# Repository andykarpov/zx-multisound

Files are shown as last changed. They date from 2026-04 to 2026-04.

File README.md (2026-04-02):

## ZX-MultiSound
Sound card for ZX Spectrum (NemoBus).

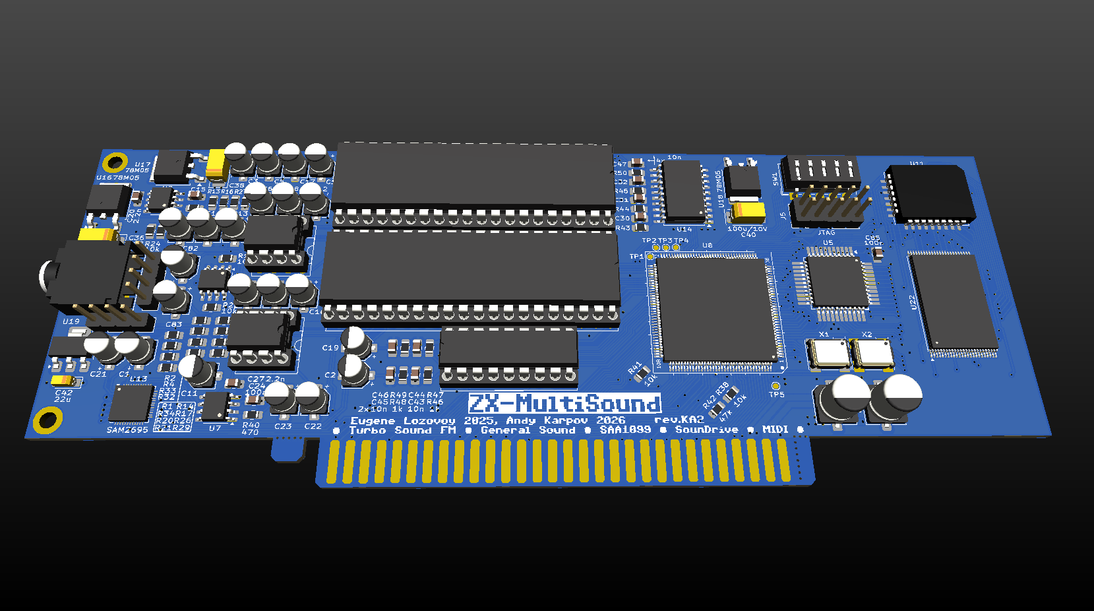
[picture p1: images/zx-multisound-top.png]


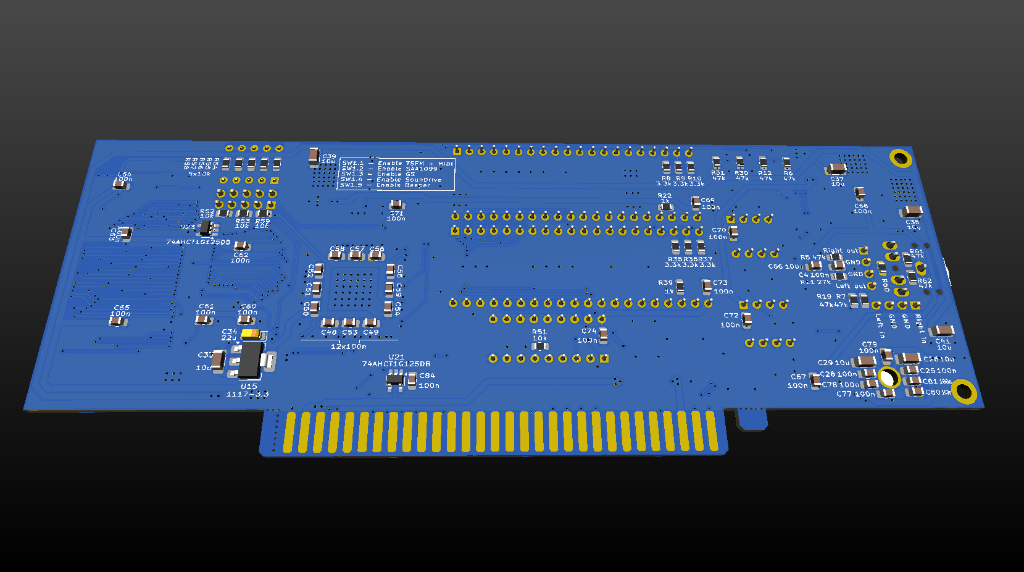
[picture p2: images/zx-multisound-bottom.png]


### Tech specs
* TurboSound FM (2xYM2203)
* General Sound (16MHz, 1024Kb of RAM)
* SAA1099 (use port #FF/#1FF to access SAA chip, write #F7/#FF to #FFFD port to enable/disable SAA)
* SounDrive (ports #0F, #1F, #4F, #5F)
* MIDI synthesizer (controlled via YM(AY) chip - compatible with ZX Spectrum 128K / ZXUNO)
* Low profile PCB: 170x64mm
* 5V and 12V power required
* 4x 1-bit digital DACs for GS and SounDrive

### Changelog & current status
* Rev.A - first release. Please note the [errata](pcb/rev.A/ERRATA.txt);
* Rev.A1 - fixed known rev.A issues. Please note the [errata](pcb/rev.A1/ERRATA.txt).
* Rev.A2:
    * Fixed Z80 clocking - added buffer;
    * Fixed 3.5mm jack footprint swapped left-right channels;
    * Fixed misplaced R20 and R34 labels on silkscreen;
    * 74LVC1G125DB replaced by 74AHCT1G125DB;
    * C3,C5,C17,C18 slightly moved left;
    * Added ledge on edge connector;
    * Improved SAM2695 footprint for hand soldering.
* Rev.KA2:
    * Single SRAM chip 2mb

Sound card has been tested only with ZX Evolution. You can use it with another computer at your own risk.

### Related projects
* Turbo Sound FM - [link](http://www.nedopc.com/TURBOSOUND/ts-fm.php)
* ZXM-SoundCard - [link](http://micklab.ru/My%20Soundcard/ZXMSoundCard.htm)
* ZXM-GeneralSound - [link](http://micklab.ru/My%20Soundcard/ZXMGeneralSound.htm)
* NeoGS - [link](http://www.nedopc.com/gs/ngs.php)

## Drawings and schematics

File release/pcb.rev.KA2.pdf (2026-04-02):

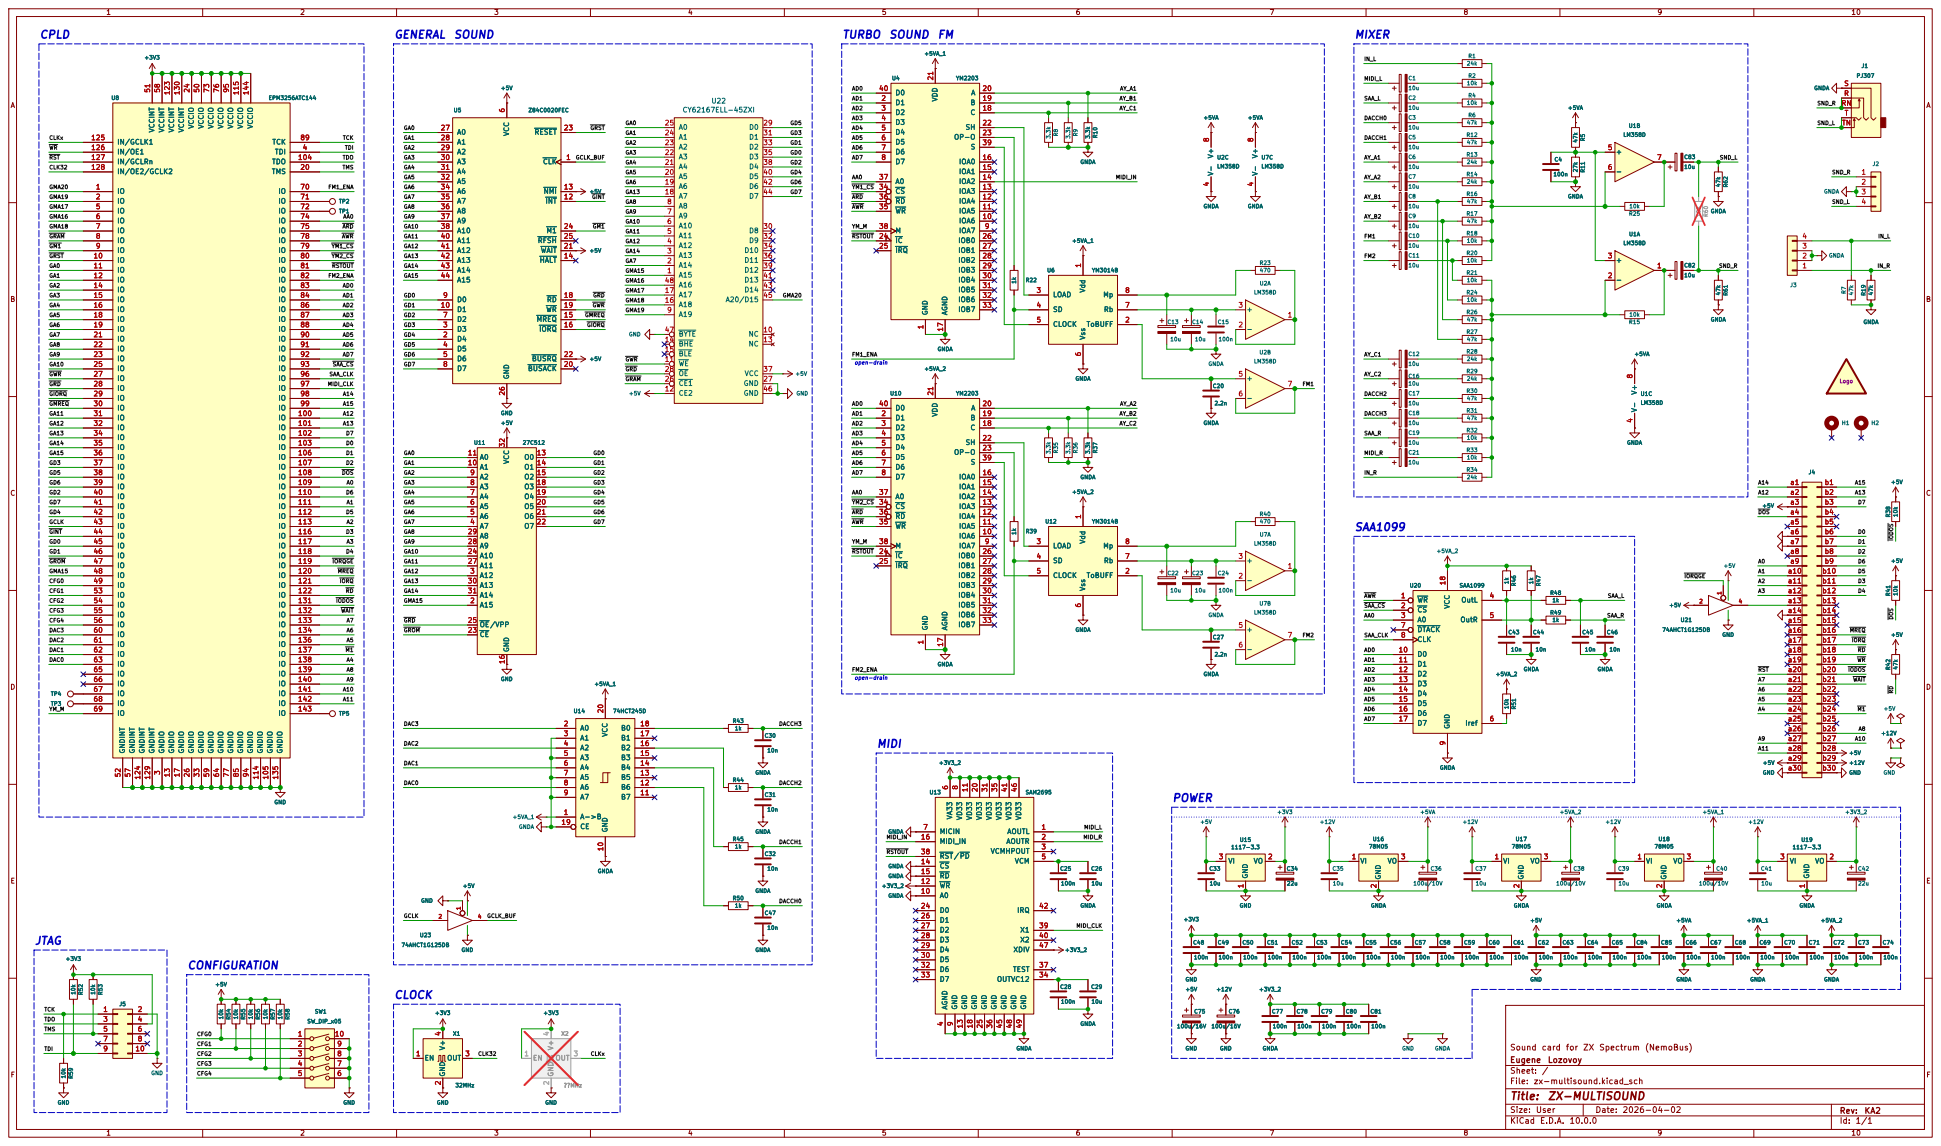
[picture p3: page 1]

open-drain TURBO SOUND FM

Sound card for ZX Spectrum (NemoBus)
Eugene Lozovoy
Sheet: /
F Date: 2026-04-02 KiCad E.D.A. 10.0.0
File: zx-multisound.kicad_sch
Title: ZX-MULTISOUND

GND

Size: User | Rev: KA2

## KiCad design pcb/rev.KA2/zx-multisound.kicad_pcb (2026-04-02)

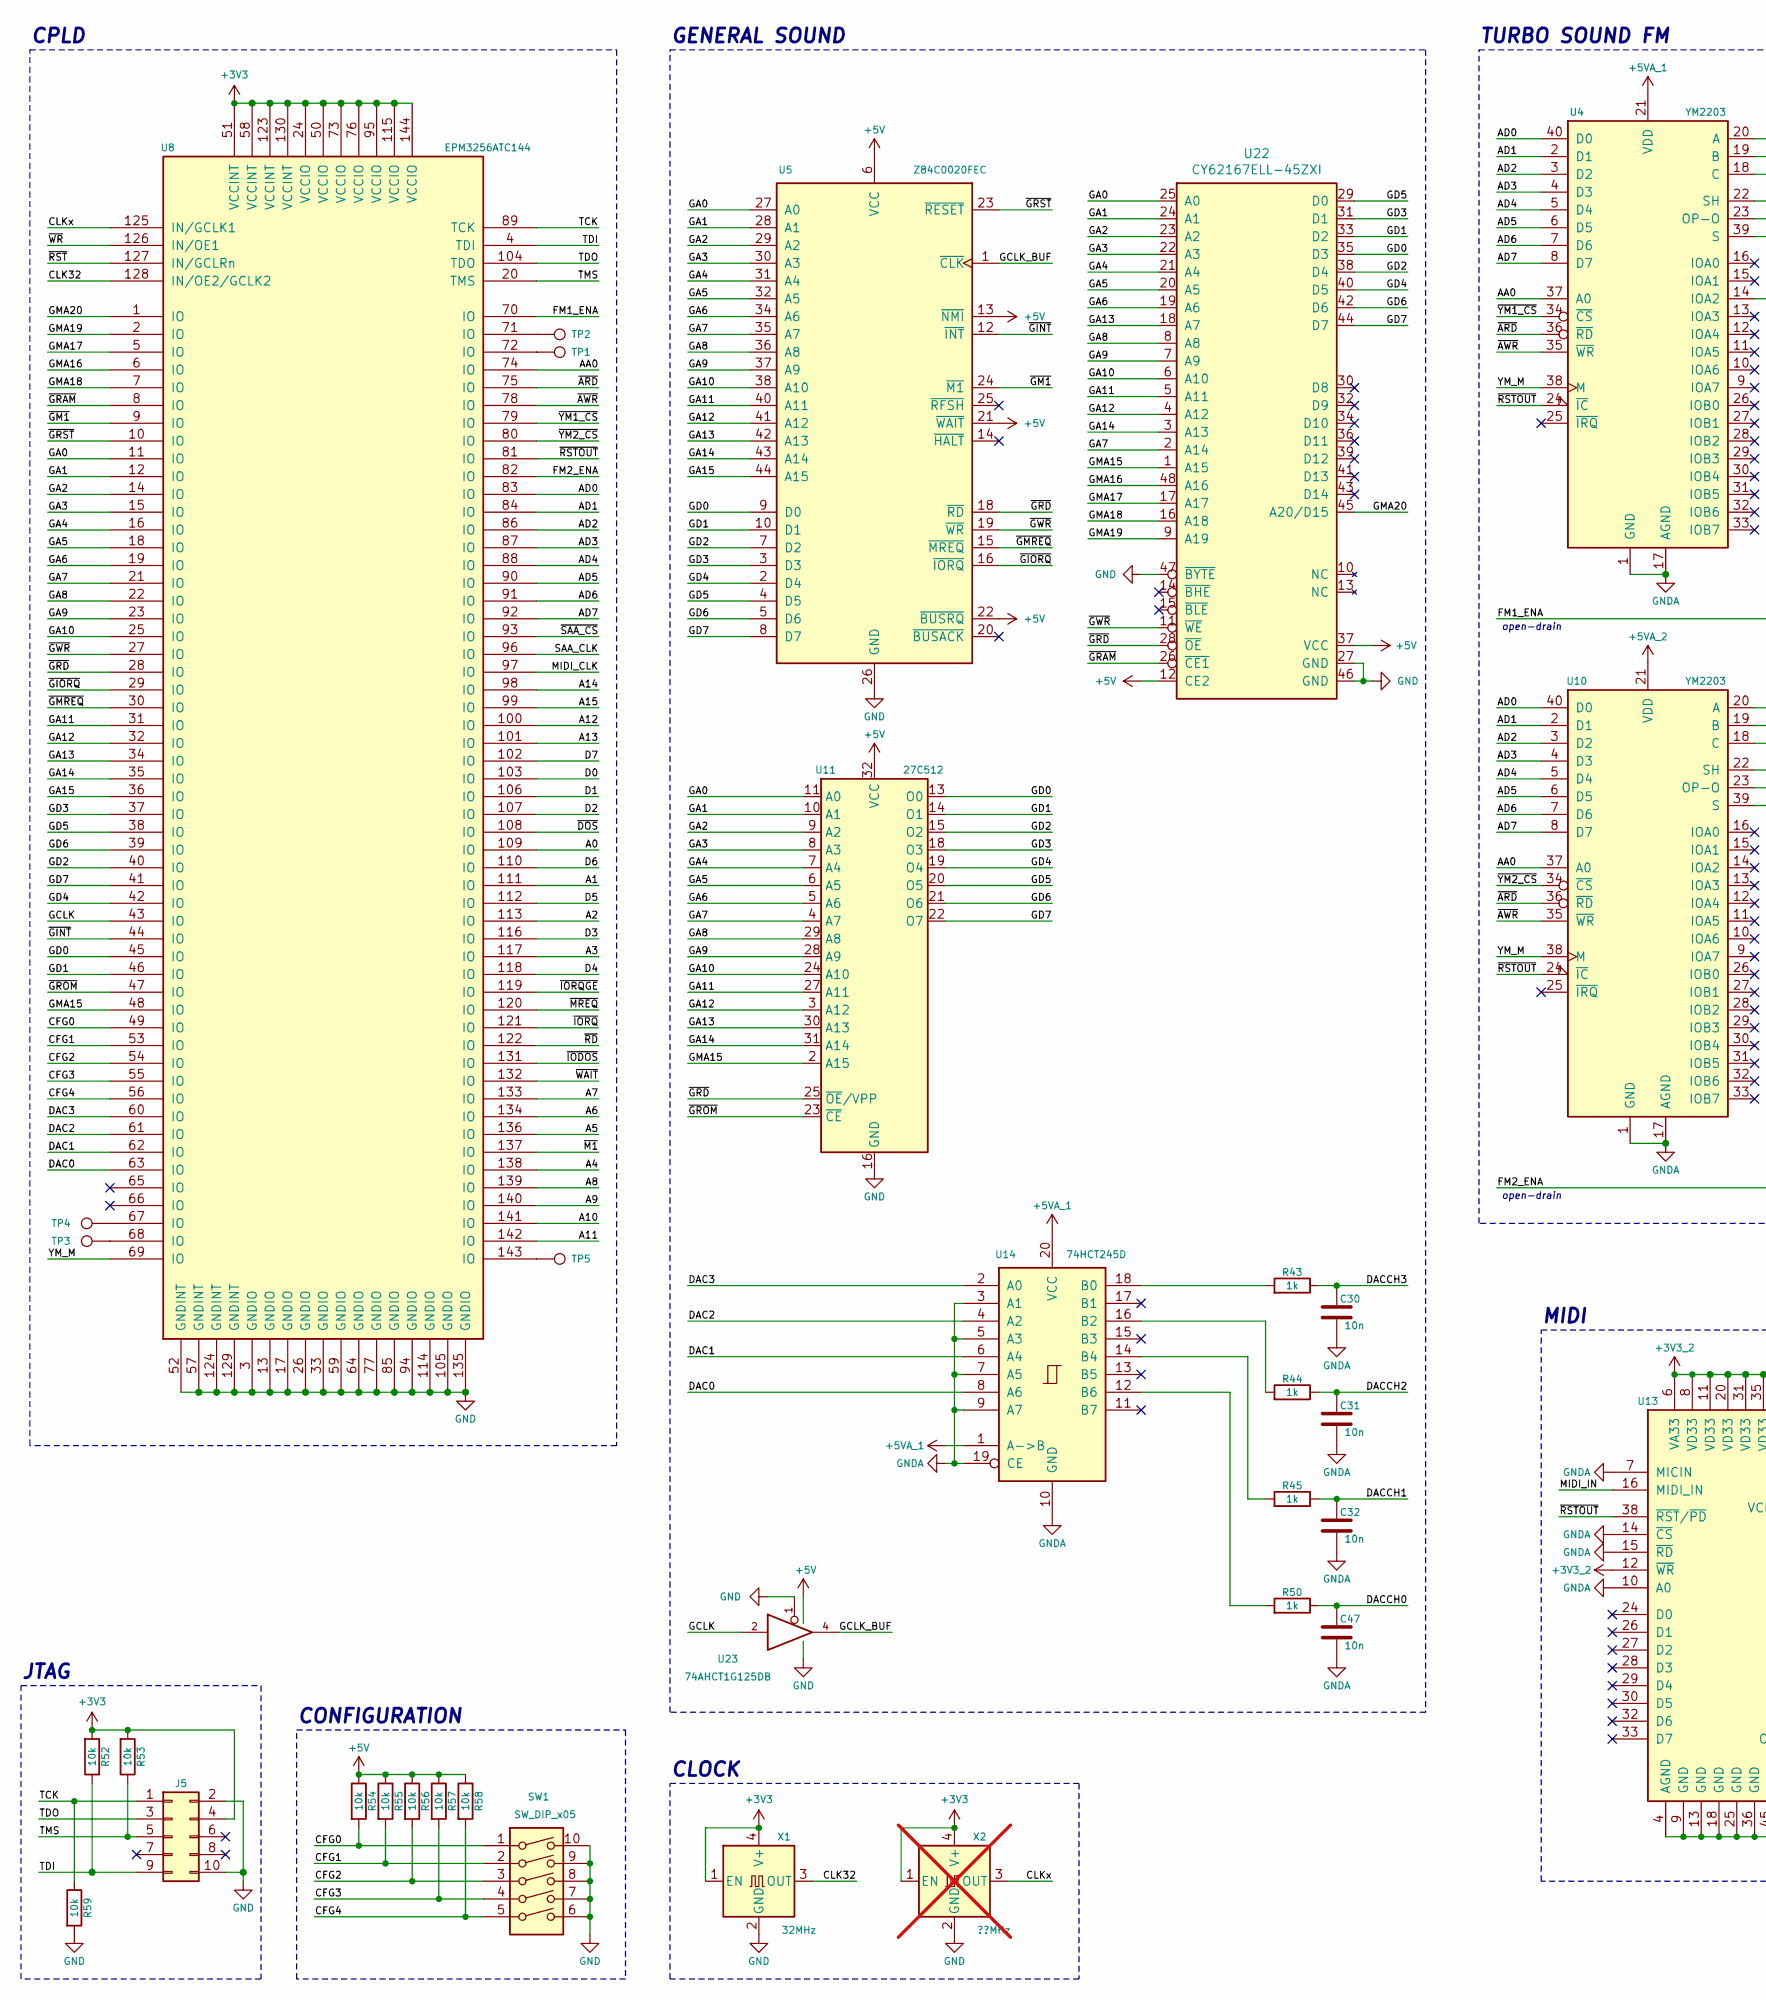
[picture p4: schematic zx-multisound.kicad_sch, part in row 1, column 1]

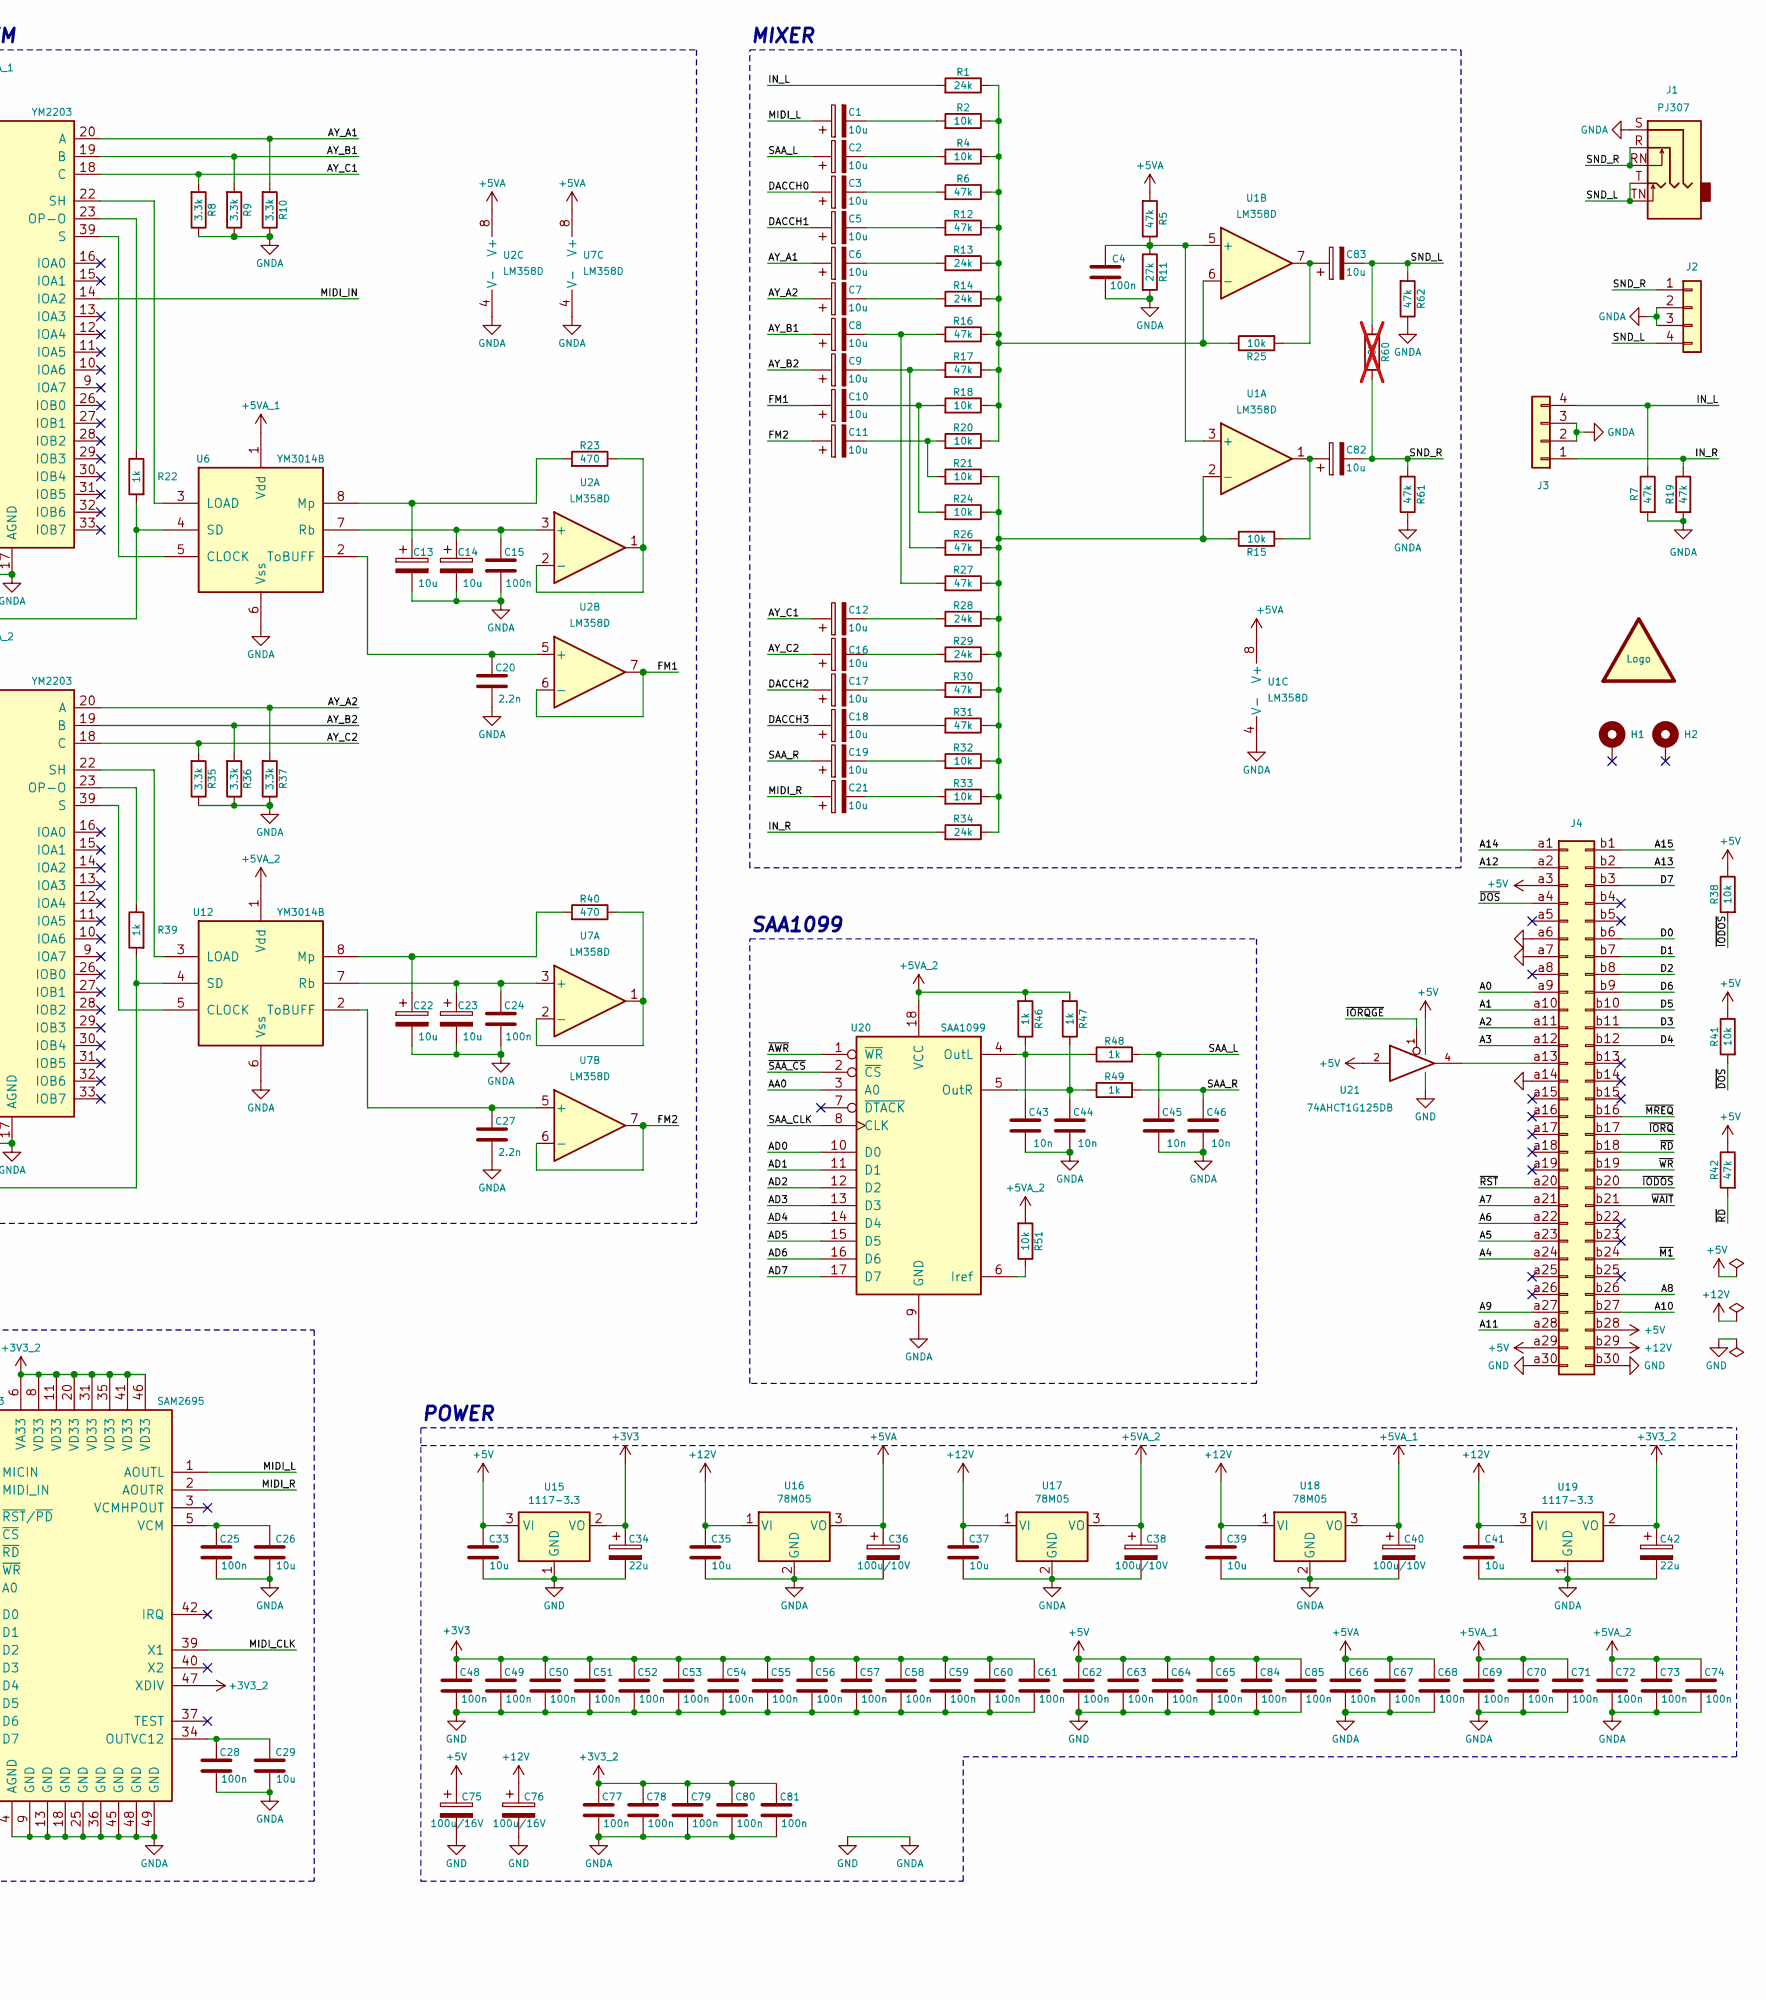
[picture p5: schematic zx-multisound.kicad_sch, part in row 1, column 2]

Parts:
C1, C2, C3, C5, C6, C7, C8, C9, C10, C11, C12, C13, C14, C16, C17, C18, C19, C21, C22, C23, C82, C83: 10u; CP_Elec_4x5.4
C4, C15, C24, C25, C28, C48, C49, C50, C51, C52, C53, C54, C55, C56, C57, C58, C59, C60, C61, C62, C63, C64, C65, C66, C67, C68, C69, C70, C71, C72, C73, C74, C77, C78, C79, C80, C81, C84, C85: 100n; C_0805_2012Metric_Pad1.18x1.45mm_HandSolder
C20, C27: 2.2n; C_0805_2012Metric_Pad1.18x1.45mm_HandSolder
C26, C29, C33, C35, C37, C39, C41: 10u; C_1206_3216Metric_Pad1.33x1.80mm_HandSolder
C30, C31, C32, C43, C44, C45, C46, C47: 10n; C_0805_2012Metric_Pad1.18x1.45mm_HandSolder
C34, C42: 22u; CP_EIA-3216-18_Kemet-A_Pad1.58x1.35mm_HandSolder
C36, C38, C40: 100u/10V; CP_EIA-6032-28_Kemet-C_Pad2.25x2.35mm_HandSolder
C75, C76: 100u/16V; CP_Elec_6.3x7.7
H1, H2: MountingHole_Pad; MountingHole_2.7mm_M2.5_DIN965_Pad
J1: PJ307; PJ-307
J2, J3: Conn_01x04; PinHeader_1x04_P2.54mm_Vertical
J4: Conn_02x30_Row_Letter_First; ZX_NEMO_60_EDGE
J5: Conn_02x05_Odd_Even; PinHeader_2x05_P2.54mm_Vertical
LOGO1: graphic; black-mage-12.5x8.6
R1, R13, R14, R28, R29, R34: 24k; R_0805_2012Metric_Pad1.20x1.40mm_HandSolder
R2, R4, R15, R18, R20, R21, R24, R25, R32, R33, R38, R41, R51, R52, R53, R54, R55, R56, R57, R58, R59: 10k; R_0805_2012Metric_Pad1.20x1.40mm_HandSolder
R5, R6, R7, R12, R16, R17, R19, R26, R27, R30, R31, R42, R61, R62: 47k; R_0805_2012Metric_Pad1.20x1.40mm_HandSolder
R8, R9, R10, R35, R36, R37: 3.3k; R_0805_2012Metric_Pad1.20x1.40mm_HandSolder
R11: 27k; R_0805_2012Metric_Pad1.20x1.40mm_HandSolder
R22, R39, R43, R44, R45, R46, R47, R48, R49, R50: 1k; R_0805_2012Metric_Pad1.20x1.40mm_HandSolder
R23, R40: 470; R_0805_2012Metric_Pad1.20x1.40mm_HandSolder
R60: 10K; R_0805_2012Metric_Pad1.20x1.40mm_HandSolder; not fitted
SW1: SW_DIP_x05; SW_DIP_SPSTx05_Slide_6.7x14.26mm_W7.62mm_P2.54mm_LowProfile
TP1, TP2, TP3, TP4, TP5: TestPoint; TestPoint_Pad_D1.0mm
U1, U2, U7: LM358D; SOIC-8_3.9x4.9mm_P1.27mm
U4, U10: YM2203; DIP-40_W15.24mm_Socket
U5: Z84C0020FEC; TQFP-44_14x14mm_P0.8mm
U6, U12: YM3014B; DIP-8_W7.62mm_Socket
U8: EPM3256ATC144; TQFP-144_20x20mm_P0.5mm
U11: 27C512; PLCC-32_11.4x14.0mm_P1.27mm-longpads
U13: SAM2695; QFN-48-1EP_6x6mm_P0.4mm_EP4.2x4.2mm
U14: 74HCT245D; SOIC-20W_7.5x12.8mm_P1.27mm
U15, U19: 1117-3.3; SOT-223-3_TabPin2
U16, U17, U18: 78M05; TO-252-2
U20: SAA1099; DIP-18_W7.62mm_Socket
U21, U23: 74AHCT1G125DB; SOT-23-5_HandSoldering
U22: CY62167ELL-45ZXI; TSOP-I-48_18.4x12mm_P0.5mm
X1: 32MHz; Oscillator_SMD_7050_7.0x5.0mm
X2: ??MHz; Oscillator_SMD_7050_7.0x5.0mm; not fitted

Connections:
+3V3: C34.1, C48.1, C49.1, C50.1, C51.1, C52.1, C53.1, C54.1, C55.1, C56.1, C57.1, C58.1, C59.1, C60.2, C61.2, J5.4, R52.2, R53.2, U8.24 (VCCIO), U8.50 (VCCIO), U8.51 (VCCINT), U8.58 (VCCINT), U8.73 (VCCIO), U8.76 (VCCIO), U8.95 (VCCIO), U8.115 (VCCIO), U8.123 (VCCINT), U8.130 (VCCINT), U8.144 (VCCIO), U15.2 (VO), X1.1 (EN), X1.4 (V+), X2.1 (EN), X2.4 (V+)
+3V3_2: C42.1, C77.1, C78.1, C79.1, C80.1, C81.1, U13.6 (VA33), U13.8 (VD33), U13.11 (VD33), U13.12 (~WR), U13.20 (VD33), U13.31 (VD33), U13.35 (VD33), U13.41 (VD33), U13.46 (VD33), U13.47 (XDIV), U19.2 (VO)
+5V: C33.1, C62.2, C63.2, C64.2, C65.2, C75.1, C84.2, C85.2, J4.a3, J4.a29, J4.b28, R38.1, R41.1, R42.1, R54.1, R55.1, R56.1, R57.1, R58.1, U5.6 (VCC), U5.13 (~NMI), U5.21 (~WAIT), U5.22 (~BUSRQ), U11.32 (VCC), U15.3 (VI), U21.2, U21.5 (VCC), U22.12 (CE2), U22.37 (VCC), U23.5 (VCC)
+5VA: C36.1, C66.2, C67.2, C68.2, R5.2, U1.8 (V+), U2.8 (V+), U7.8 (V+), U16.3 (VO)
+5VA_1: C40.1, C69.2, C70.2, C71.2, U4.21 (VDD), U6.1 (Vdd), U14.1 (A->B), U14.20 (VCC), U18.3 (VO)
+5VA_2: C38.1, C72.2, C73.2, C74.2, R46.2, R47.2, R51.2, U10.21 (VDD), U12.1 (Vdd), U17.3 (VO), U20.18 (VCC)
+12V: C35.1, C37.1, C39.1, C41.1, C76.1, J4.b29, U16.1 (VI), U17.1 (VI), U18.1 (VI), U19.3 (VI)
/A0: J4.a9, U8.109 (IO)
/A1: J4.a10, U8.111 (IO)
/A2: J4.a11, U8.113 (IO)
/A3: J4.a12, U8.117 (IO)
/A4: J4.a24, U8.138 (IO)
/A5: J4.a23, U8.136 (IO)
/A6: J4.a22, U8.134 (IO)
/A7: J4.a21, U8.133 (IO)
/A8: J4.b26, U8.139 (IO)
/A9: J4.a27, U8.140 (IO)
/A10: J4.b27, U8.141 (IO)
/A11: J4.a28, U8.142 (IO)
/A12: J4.a2, U8.100 (IO)
/A13: J4.b2, U8.101 (IO)
/A14: J4.a1, U8.98 (IO)
/A15: J4.b1, U8.99 (IO)
/AA0: U4.37 (A0), U8.74 (IO), U10.37 (A0), U20.3 (A0)
/AD0: U4.40 (D0), U8.83 (IO), U10.40 (D0), U20.10 (D0)
/AD1: U4.2 (D1), U8.84 (IO), U10.2 (D1), U20.11 (D1)
/AD2: U4.3 (D2), U8.86 (IO), U10.3 (D2), U20.12 (D2)
/AD3: U4.4 (D3), U8.87 (IO), U10.4 (D3), U20.13 (D3)
/AD4: U4.5 (D4), U8.88 (IO), U10.5 (D4), U20.14 (D4)
/AD5: U4.6 (D5), U8.90 (IO), U10.6 (D5), U20.15 (D5)
/AD6: U4.7 (D6), U8.91 (IO), U10.7 (D6), U20.16 (D6)
/AD7: U4.8 (D7), U8.92 (IO), U10.8 (D7), U20.17 (D7)
/AY_A1: C6.1, R10.2, U4.20 (A)
/AY_A2: C7.1, R37.2, U10.20 (A)
/AY_B1: C8.1, R9.2, U4.19 (B)
/AY_B2: C9.1, R36.2, U10.19 (B)
/AY_C1: C12.1, R8.2, U4.18 (C)
/AY_C2: C16.1, R35.2, U10.18 (C)
/CFG0: R54.2, SW1.1, U8.49 (IO)
/CFG1: R55.2, SW1.2, U8.53 (IO)
/CFG2: R56.2, SW1.3, U8.54 (IO)
/CFG3: R57.2, SW1.4, U8.55 (IO)
/CFG4: R58.2, SW1.5, U8.56 (IO)
/CLK32: U8.128 (IN/OE2/GCLK2), X1.3 (OUT)
/CLKx: U8.125 (IN/GCLK1), X2.3 (OUT)
/D0: J4.b6, U8.103 (IO)
/D1: J4.b7, U8.106 (IO)
/D2: J4.b8, U8.107 (IO)
/D3: J4.b11, U8.116 (IO)
/D4: J4.b12, U8.118 (IO)
/D5: J4.b10, U8.112 (IO)
/D6: J4.b9, U8.110 (IO)
/D7: J4.b3, U8.102 (IO)
/DAC0: U8.63 (IO), U14.8 (A6)
/DAC1: U8.62 (IO), U14.6 (A4)
/DAC2: U8.61 (IO), U14.4 (A2)
/DAC3: U8.60 (IO), U14.2 (A0)
/DACCH0: C3.1, C47.1, R50.1
/DACCH1: C5.1, C32.1, R45.1
/DACCH2: C17.1, C31.1, R44.1
/DACCH3: C18.1, C30.1, R43.1
/FM1: C10.1, U2.6 (-), U2.7
/FM1_ENA: R22.2, U6.4 (SD), U8.70 (IO)
/FM2: C11.1, U7.6 (-), U7.7
/FM2_ENA: R39.2, U8.82 (IO), U12.4 (SD)
/GA0: U5.27 (A0), U8.11 (IO), U11.11 (A0), U22.25 (A0)
/GA1: U5.28 (A1), U8.12 (IO), U11.10 (A1), U22.24 (A1)
/GA2: U5.29 (A2), U8.14 (IO), U11.9 (A2), U22.23 (A2)
/GA3: U5.30 (A3), U8.15 (IO), U11.8 (A3), U22.22 (A3)
/GA4: U5.31 (A4), U8.16 (IO), U11.7 (A4), U22.21 (A4)
/GA5: U5.32 (A5), U8.18 (IO), U11.6 (A5), U22.20 (A5)
/GA6: U5.34 (A6), U8.19 (IO), U11.5 (A6), U22.19 (A6)
/GA7: U5.35 (A7), U8.21 (IO), U11.4 (A7), U22.2 (A14)
/GA8: U5.36 (A8), U8.22 (IO), U11.29 (A8), U22.8 (A8)
/GA9: U5.37 (A9), U8.23 (IO), U11.28 (A9), U22.7 (A9)
/GA10: U5.38 (A10), U8.25 (IO), U11.24 (A10), U22.6 (A10)
/GA11: U5.40 (A11), U8.31 (IO), U11.27 (A11), U22.5 (A11)
/GA12: U5.41 (A12), U8.32 (IO), U11.3 (A12), U22.4 (A12)
/GA13: U5.42 (A13), U8.34 (IO), U11.30 (A13), U22.18 (A7)
/GA14: U5.43 (A14), U8.35 (IO), U11.31 (A14), U22.3 (A13)
/GA15: U5.44 (A15), U8.36 (IO)
/GCLK: U8.43 (IO), U23.2
/GCLK_BUF: U5.1 (~CLK), U23.4
/GD0: U5.9 (D0), U8.45 (IO), U11.13 (O0), U22.35 (D3)
/GD1: U5.10 (D1), U8.46 (IO), U11.14 (O1), U22.33 (D2)
/GD2: U5.7 (D2), U8.40 (IO), U11.15 (O2), U22.38 (D4)
/GD3: U5.3 (D3), U8.37 (IO), U11.18 (O3), U22.31 (D1)
/GD4: U5.2 (D4), U8.42 (IO), U11.19 (O4), U22.40 (D5)
/GD5: U5.4 (D5), U8.38 (IO), U11.20 (O5), U22.29 (D0)
/GD6: U5.5 (D6), U8.39 (IO), U11.21 (O6), U22.42 (D6)
/GD7: U5.8 (D7), U8.41 (IO), U11.22 (O7), U22.44 (D7)
/GMA15: U8.48 (IO), U11.2 (A15), U22.1 (A15)
/GMA16: U8.6 (IO), U22.48 (A16)
/GMA17: U8.5 (IO), U22.17 (A17)
/GMA18: U8.7 (IO), U22.16 (A18)
/GMA19: U8.2 (IO), U22.9 (A19)
/GMA20: U8.1 (IO), U22.45 (A20/D15)
/IN_L: J3.4, R1.2, R7.1
/IN_R: J3.1, R19.1, R34.2
/MIDI_CLK: U8.97 (IO), U13.39 (X1)
/MIDI_IN: U4.14 (IOA2), U13.16 (MIDI_IN)
/MIDI_L: C1.1, U13.1 (AOUTL)
/MIDI_R: C21.1, U13.2 (AOUTR)
/SAA_CLK: U8.96 (IO), U20.8 (CLK)
/SAA_L: C2.1, C45.1, R48.2
/SAA_R: C19.1, C46.1, R49.2
/SND_L: C83.2, J1.T, J1.TN, J2.4, R60.2, R62.2
/SND_R: C82.2, J1.R, J1.RN, J2.1, R60.1, R61.2
/TCK: J5.1, R59.1, U8.89 (TCK)
/TDI: J5.9, R52.1, U8.4 (TDI)
/TDO: J5.3, U8.104 (TDO)
/TMS: J5.5, R53.1, U8.20 (TMS)
/YM_M: U4.38 (M), U8.69 (IO), U10.38 (M)
/~ARD: U4.36 (~RD), U8.75 (IO), U10.36 (~RD)
/~AWR: U4.35 (~WR), U8.78 (IO), U10.35 (~WR), U20.1 (~WR)
/~DOS: J4.a4, R41.2, U8.108 (IO)
/~GINT: U5.12 (~INT), U8.44 (IO)
/~GIORQ: U5.16 (~IORQ), U8.29 (IO)
/~GM1: U5.24 (~M1), U8.9 (IO)
/~GMREQ: U5.15 (~MREQ), U8.30 (IO)
/~GRAM: U8.8 (IO), U22.26 (~CE1)
/~GRD: U5.18 (~RD), U8.28 (IO), U11.25 (~OE/VPP), U22.28 (~OE)
/~GROM: U8.47 (IO), U11.23 (~CE)
/~GRST: U5.23 (~RESET), U8.10 (IO)
/~GWR: U5.19 (~WR), U8.27 (IO), U22.11 (~WE)
/~IODOS: J4.b20, R38.2, U8.131 (IO)
/~IORQGE: U8.119 (IO), U21.1
/~IORQ: J4.b17, U8.121 (IO)
/~M1: J4.b24, U8.137 (IO)
/~MREQ: J4.b16, U8.120 (IO)
/~RD: J4.b18, R42.2, U8.122 (IO)
/~RSTOUT: U4.24 (~IC), U8.81 (IO), U10.24 (~IC), U13.38 (~RST/~PD)
/~RST: J4.a20, U8.127 (IN/GCLRn)
/~SAA_CS: U8.93 (IO), U20.2 (~CS)
/~WAIT: J4.b21, U8.132 (IO)
/~WR: J4.b19, U8.126 (IN/OE1)
/~YM1_CS: U4.34 (~CS), U8.79 (IO)
/~YM2_CS: U8.80 (IO), U10.34 (~CS)
GND: C4.1, C13.2, C14.2, C15.2, C20.2, C22.2, C23.2, C24.2, C25.2, C26.2, C27.2, C28.2, C29.2, C30.2, C31.2, C32.2, C33.2, C34.2, C35.2, C36.2, C37.2, C38.2, C39.2, C40.2, C41.2, C42.2, C43.2, C44.2, C45.2, C46.2, C47.2, C48.2, C49.2, C50.2, C51.2, C52.2, C53.2, C54.2, C55.2, C56.2, C57.2, C58.2, C59.2, C60.1, C61.1, C62.1, C63.1, C64.1, C65.1, C66.1, C67.1, C68.1, C69.1, C70.1, C71.1, C72.1, C73.1, C74.1, C75.2, C76.2, C77.2, C78.2, C79.2, C80.2, C81.2, C84.1, C85.1, J1.S, J2.2, J2.3, J3.2, J3.3, J4.a6, J4.a7, J4.a14, J4.a30, J4.b30, J5.2, J5.10, R7.2, R8.1, R9.1, R10.1, R11.2, R19.2, R35.1, R36.1, R37.1, R59.2, R61.1, R62.1, SW1.6, SW1.7, SW1.8, SW1.9, SW1.10, U1.4 (V-), U2.4 (V-), U4.1 (GND), U4.17 (AGND), U5.26 (GND), U6.6 (Vss), U7.4 (V-), U8.3 (GNDIO), U8.13 (GNDIO), U8.17 (GNDIO), U8.26 (GNDIO), U8.33 (GNDIO), U8.52 (GNDINT), U8.57 (GNDINT), U8.59 (GNDIO), U8.64 (GNDIO), U8.77 (GNDIO), U8.85 (GNDIO), U8.94 (GNDIO), U8.105 (GNDIO), U8.114 (GNDIO), U8.124 (GNDINT), U8.129 (GNDINT), U8.135 (GNDIO), U10.1 (GND), U10.17 (AGND), U11.16 (GND), U12.6 (Vss), U13.4 (AGND), U13.7 (MICIN), U13.9 (GND), U13.10 (A0), U13.13 (GND), U13.14 (~CS), U13.15 (~RD), U13.18 (GND), U13.25 (GND), U13.36 (GND), U13.45 (GND), U13.48 (GND), U13.49 (GND), U14.3 (A1), U14.5 (A3), U14.7 (A5), U14.9 (A7), U14.10 (GND), U14.19 (CE), U15.1 (GND), U16.2 (GND), U17.2 (GND), U18.2 (GND), U19.1 (GND), U20.9 (GND), U21.3 (GND), U22.27 (GND), U22.46 (GND), U22.47 (~BYTE), U23.1, U23.3 (GND), X1.2 (GND), X2.2 (GND)
unnamed: C1.2, R2.2
unnamed: C2.2, R4.2
unnamed: C3.2, R6.2
unnamed: C5.2, R12.2
unnamed: C6.2, R13.2
unnamed: C7.2, R14.2
unnamed: C8.2, R16.2, R27.2
unnamed: C9.2, R17.2, R26.2
unnamed: C10.2, R18.2, R24.2
unnamed: C11.2, R20.2, R21.2
unnamed: C12.2, R28.2
unnamed: C16.2, R29.2
unnamed: C17.2, R30.2
unnamed: C18.2, R31.2
unnamed: C19.2, R32.2
unnamed: C21.2, R33.2
unnamed: C82.1, R15.2, U1.1
unnamed: C83.1, R25.2, U1.7
unnamed: J4.a13, U21.4
unnamed: TP1.1 (1_1), U8.72 (IO)
unnamed: TP2.1 (1_1), U8.71 (IO)
unnamed: TP3.1 (1_1), U8.68 (IO)
unnamed: TP4.1 (1_1), U8.67 (IO)
unnamed: TP5.1 (1_1), U8.143 (IO)
unnamed: C4.2, R5.1, R11.1, U1.3 (+), U1.5 (+)
unnamed: R15.1, R21.1, R24.1, R26.1, R27.1, R28.1, R29.1, R30.1, R31.1, R32.1, R33.1, R34.1, U1.2 (-)
unnamed: R1.1, R2.1, R4.1, R6.1, R12.1, R13.1, R14.1, R16.1, R17.1, R18.1, R20.1, R25.1, U1.6 (-)
unnamed: C14.1, C15.1, U2.3 (+), U6.7 (Rb)
unnamed: R23.1, U2.1, U2.2 (-)
unnamed: C20.1, U2.5 (+), U6.2 (ToBUFF)
unnamed: R22.1, U4.23 (OP-O)
unnamed: U4.39 (S), U6.5 (CLOCK)
unnamed: U4.22 (SH), U6.3 (LOAD)
unnamed: C13.1, R23.2, U6.8 (Mp)
unnamed: R40.1, U7.1, U7.2 (-)
unnamed: R39.1, U10.23 (OP-O)
unnamed: U10.39 (S), U12.5 (CLOCK)
unnamed: U10.22 (SH), U12.3 (LOAD)
unnamed: C22.1, R40.2, U12.8 (Mp)
unnamed: C23.1, C24.1, U7.3 (+), U12.7 (Rb)
unnamed: C27.1, U7.5 (+), U12.2 (ToBUFF)
unnamed: C28.1, C29.1, U13.34 (OUTVC12)
unnamed: C25.1, C26.1, U13.5 (VCM)
unnamed: R43.2, U14.18 (B0)
unnamed: R44.2, U14.16 (B2)
unnamed: R45.2, U14.14 (B4)
unnamed: R50.2, U14.12 (B6)
unnamed: R51.1, U20.6 (Iref)
unnamed: C43.1, R46.1, R48.1, U20.4 (OutL)
unnamed: C44.1, R47.1, R49.1, U20.5 (OutR)

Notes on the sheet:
SAA1099
CONFIGURATION
open-drain
GENERAL SOUND
TURBO SOUND FM
MIXER
CPLD
JTAG
POWER
MIDI
CLOCK

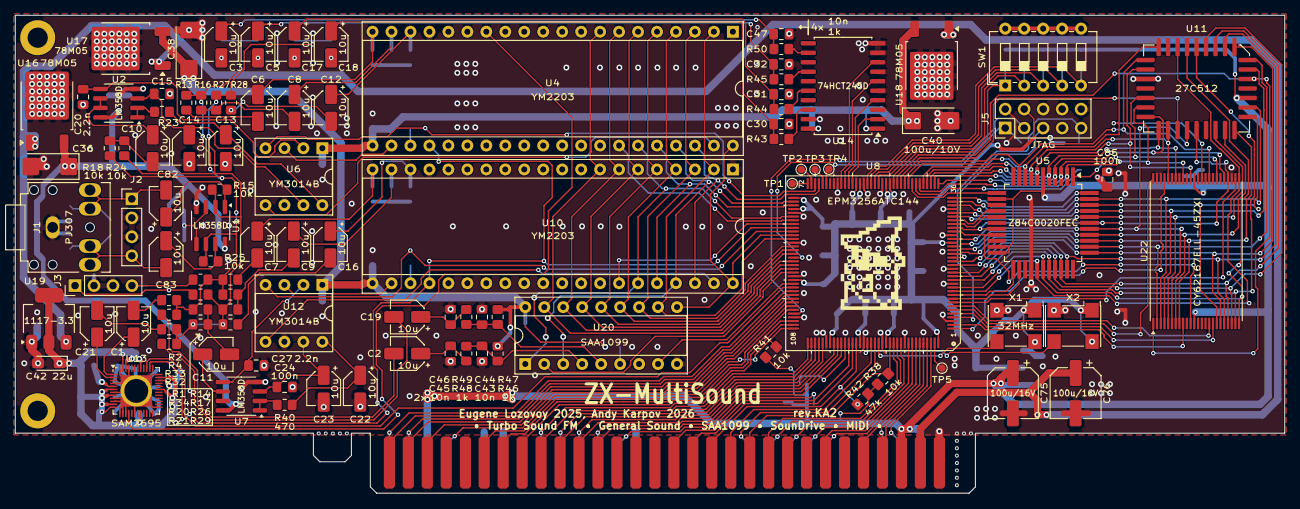
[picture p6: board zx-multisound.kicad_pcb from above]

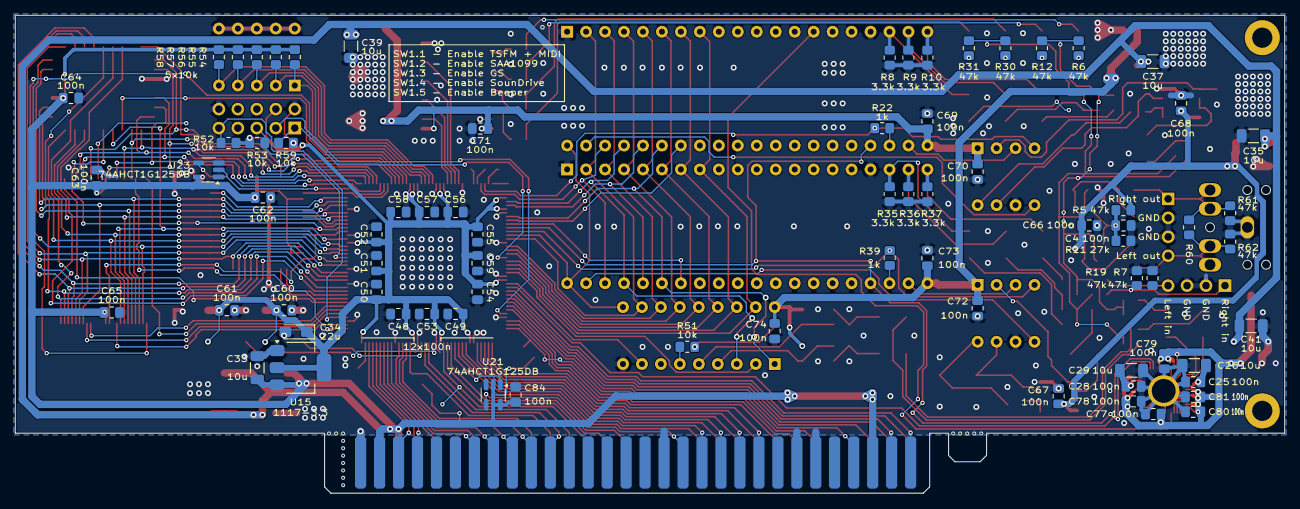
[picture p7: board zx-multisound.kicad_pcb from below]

Board: 2 copper layers, 170.0 x 64.0 mm, 183 parts (75 on the bottom side), 189 nets.

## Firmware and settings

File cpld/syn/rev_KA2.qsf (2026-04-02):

# -------------------------------------------------------------------------- #
#
# Copyright (C) 1991-2013 Altera Corporation
# Your use of Altera Corporation's design tools, logic functions 
# and other software and tools, and its AMPP partner logic 
# functions, and any output files from any of the foregoing 
# (including device programming or simulation files), and any 
# associated documentation or information are expressly subject 
# to the terms and conditions of the Altera Program License 
# Subscription Agreement, Altera MegaCore Function License 
# Agreement, or other applicable license agreement, including, 
# without limitation, that your use is for the sole purpose of 
# programming logic devices manufactured by Altera and sold by 
# Altera or its authorized distributors.  Please refer to the 
# applicable agreement for further details.
#
# -------------------------------------------------------------------------- #
#
# Quartus II 64-Bit
# Version 13.0.1 Build 232 06/12/2013 Service Pack 1 SJ Full Version
# Date created = 12:04:27  October 04, 2020
#
# -------------------------------------------------------------------------- #
#
# Notes:
#
# 1) The default values for assignments are stored in the file:
#		zx_multisound_assignment_defaults.qdf
#    If this file doesn't exist, see file:
#		assignment_defaults.qdf
#
# 2) Altera recommends that you do not modify this file. This
#    file is updated automatically by the Quartus II software
#    and any changes you make may be lost or overwritten.
#
# -------------------------------------------------------------------------- #


set_global_assignment -name FAMILY MAX3000A
set_global_assignment -name DEVICE "EPM3256ATC144-10"
set_global_assignment -name TOP_LEVEL_ENTITY zx_multisound
set_global_assignment -name ORIGINAL_QUARTUS_VERSION "13.0 SP1"
set_global_assignment -name PROJECT_CREATION_TIME_DATE "12:04:27  OCTOBER 04, 2020"
set_global_assignment -name LAST_QUARTUS_VERSION "13.0 SP1"
set_global_assignment -name PROJECT_OUTPUT_DIRECTORY output
set_global_assignment -name DEVICE_FILTER_PIN_COUNT 144
set_global_assignment -name ERROR_CHECK_FREQUENCY_DIVISOR "-1"
set_global_assignment -name SDC_FILE clocks.sdc
set_global_assignment -name VERILOG_FILE ../rtl/top.v
set_global_assignment -name VHDL_INPUT_VERSION VHDL_2008
set_global_assignment -name VHDL_SHOW_LMF_MAPPING_MESSAGES OFF
set_global_assignment -name VERILOG_INPUT_VERSION SYSTEMVERILOG_2005
set_global_assignment -name VERILOG_SHOW_LMF_MAPPING_MESSAGES OFF
set_global_assignment -name MAX7000_DEVICE_IO_STANDARD "3.3-V LVTTL"
set_global_assignment -name SAVE_DISK_SPACE OFF
set_global_assignment -name TIMEQUEST_MULTICORNER_ANALYSIS OFF
set_global_assignment -name SYNTH_TIMING_DRIVEN_SYNTHESIS OFF

set_location_assignment PIN_5 -to gma[17]
set_location_assignment PIN_6 -to gma[16]
set_location_assignment PIN_7 -to gma[18]
set_location_assignment PIN_2 -to gma[19]
set_location_assignment PIN_1 -to gma[20]
set_location_assignment PIN_8 -to n_gram
set_location_assignment PIN_9 -to n_gm1
set_location_assignment PIN_10 -to n_grst
set_location_assignment PIN_11 -to ga[0]
set_location_assignment PIN_12 -to ga[1]
set_location_assignment PIN_14 -to ga[2]
set_location_assignment PIN_15 -to ga[3]
set_location_assignment PIN_16 -to ga[4]
set_location_assignment PIN_18 -to ga[5]
set_location_assignment PIN_19 -to ga[6]
set_location_assignment PIN_21 -to ga[7]
set_location_assignment PIN_22 -to ga[8]
set_location_assignment PIN_23 -to ga[9]
set_location_assignment PIN_25 -to ga[10]
set_location_assignment PIN_27 -to n_gwr
set_location_assignment PIN_28 -to n_grd
set_location_assignment PIN_29 -to n_giorq
set_location_assignment PIN_30 -to n_gmreq
set_location_assignment PIN_31 -to ga[11]
set_location_assignment PIN_32 -to ga[12]
set_location_assignment PIN_34 -to ga[13]
set_location_assignment PIN_35 -to ga[14]
set_location_assignment PIN_36 -to ga[15]
set_location_assignment PIN_37 -to gd[3]
set_location_assignment PIN_38 -to gd[5]
set_location_assignment PIN_39 -to gd[6]
set_location_assignment PIN_40 -to gd[2]
set_location_assignment PIN_41 -to gd[7]
set_location_assignment PIN_42 -to gd[4]
set_location_assignment PIN_43 -to gclk
set_location_assignment PIN_44 -to n_gint
set_location_assignment PIN_45 -to gd[0]
set_location_assignment PIN_46 -to gd[1]
set_location_assignment PIN_47 -to n_grom
set_location_assignment PIN_48 -to gma[15]
set_location_assignment PIN_49 -to cfg[0]
set_location_assignment PIN_53 -to cfg[1]
set_location_assignment PIN_54 -to cfg[2]
set_location_assignment PIN_55 -to cfg[3]
set_location_assignment PIN_56 -to cfg[4]
set_location_assignment PIN_60 -to dac3_out
set_location_assignment PIN_61 -to dac2_out
set_location_assignment PIN_62 -to dac1_out
set_location_assignment PIN_63 -to dac0_out
set_location_assignment PIN_69 -to ym_m
set_location_assignment PIN_70 -to fm1_ena
set_location_assignment PIN_74 -to aa0
set_location_assignment PIN_75 -to n_ard
set_location_assignment PIN_78 -to n_awr
set_location_assignment PIN_79 -to n_ym1_cs
set_location_assignment PIN_80 -to n_ym2_cs
set_location_assignment PIN_81 -to n_rstout
set_location_assignment PIN_82 -to fm2_ena
set_location_assignment PIN_83 -to ad[0]
set_location_assignment PIN_84 -to ad[1]
set_location_assignment PIN_86 -to ad[2]
set_location_assignment PIN_87 -to ad[3]
set_location_assignment PIN_88 -to ad[4]
set_location_assignment PIN_90 -to ad[5]
set_location_assignment PIN_91 -to ad[6]
set_location_assignment PIN_92 -to ad[7]
set_location_assignment PIN_93 -to n_saa_cs
set_location_assignment PIN_96 -to saa_clk
set_location_assignment PIN_97 -to midi_clk
set_location_assignment PIN_98 -to a[14]
set_location_assignment PIN_99 -to a[15]
set_location_assignment PIN_100 -to a[12]
set_location_assignment PIN_101 -to a[13]
set_location_assignment PIN_102 -to d[7]
set_location_assignment PIN_103 -to d[0]
set_location_assignment PIN_106 -to d[1]
set_location_assignment PIN_107 -to d[2]
set_location_assignment PIN_108 -to n_dos
set_location_assignment PIN_109 -to a[0]
set_location_assignment PIN_110 -to d[6]
set_location_assignment PIN_111 -to a[1]
set_location_assignment PIN_112 -to d[5]
set_location_assignment PIN_113 -to a[2]
set_location_assignment PIN_116 -to d[3]
set_location_assignment PIN_117 -to a[3]
set_location_assignment PIN_118 -to d[4]
set_location_assignment PIN_119 -to n_iorqge
set_location_assignment PIN_120 -to n_mreq
set_location_assignment PIN_121 -to n_iorq
set_location_assignment PIN_122 -to n_rd
set_location_assignment PIN_125 -to clkx
set_location_assignment PIN_126 -to n_wr
set_location_assignment PIN_127 -to rst_n
set_location_assignment PIN_128 -to clk32
set_location_assignment PIN_131 -to n_iodos
set_location_assignment PIN_132 -to n_wait
set_location_assignment PIN_133 -to a[7]
set_location_assignment PIN_134 -to a[6]
set_location_assignment PIN_136 -to a[5]
set_location_assignment PIN_137 -to n_m1
set_location_assignment PIN_138 -to a[4]
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

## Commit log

2026-04-02 CPLD firmware for rev.KA2
    [zx-multisound.kicad_pcb, zx-multisound.kicad_sch]
2026-04-02 Added label about SW[4]
    [zx-multisound.kicad_pcb]
2026-04-02 Updated 3D models, embed into the project
    [zx-multisound.kicad_sch]
2026-05-13 Removed pcb history
